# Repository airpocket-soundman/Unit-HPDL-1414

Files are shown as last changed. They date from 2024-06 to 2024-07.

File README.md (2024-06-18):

# Unit-HPDL-1414
HPDL-1414をM5StackのUnitにする

# BOM
M5Stamp S3
HPDL-1414

# PIN接続

|No|HPDL1414|StampS3|GROVE|
|-|-|-|-|
|1|D6 DATA INPUT|G46|
|2|D5 DATA INPUT|G43|
|3|WR WRITE(1)|G42|
|3|WR WRITE(2)|G44|
|4|A1 DIGIT SELECT|G41|
|5|A0 DIGIT SELECT|G40|
|6|VDD||
|7|GND||
|8|D0 DATA INPUT|G1|
|9|D1 DATA INPUT|G3|
|10|D2 DATA INPUT|G5|
|11|D3 DATA INPUT|G7|
|12|D4 DATA INPUT|G9|
|13|SDA|G13|
|14|SDC|G14|

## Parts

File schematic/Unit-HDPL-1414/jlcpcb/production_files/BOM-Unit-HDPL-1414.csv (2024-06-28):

Comment | Designator | Footprint | LCSC
H1 | M5Unit_Screw_Hole | unit_mounting_hole |  | 0 | 0
J1 | Conn_01x04 | HY2.0-4P |  | 0 | 0
U1 | M5StampS3 | M5StampS3 |  | 0 | 0
U2 | hpdl1414 | HPDL-1414 |  | 0 | 0
U3 | hpdl1414 | HPDL-1414 |  | 0 | 0

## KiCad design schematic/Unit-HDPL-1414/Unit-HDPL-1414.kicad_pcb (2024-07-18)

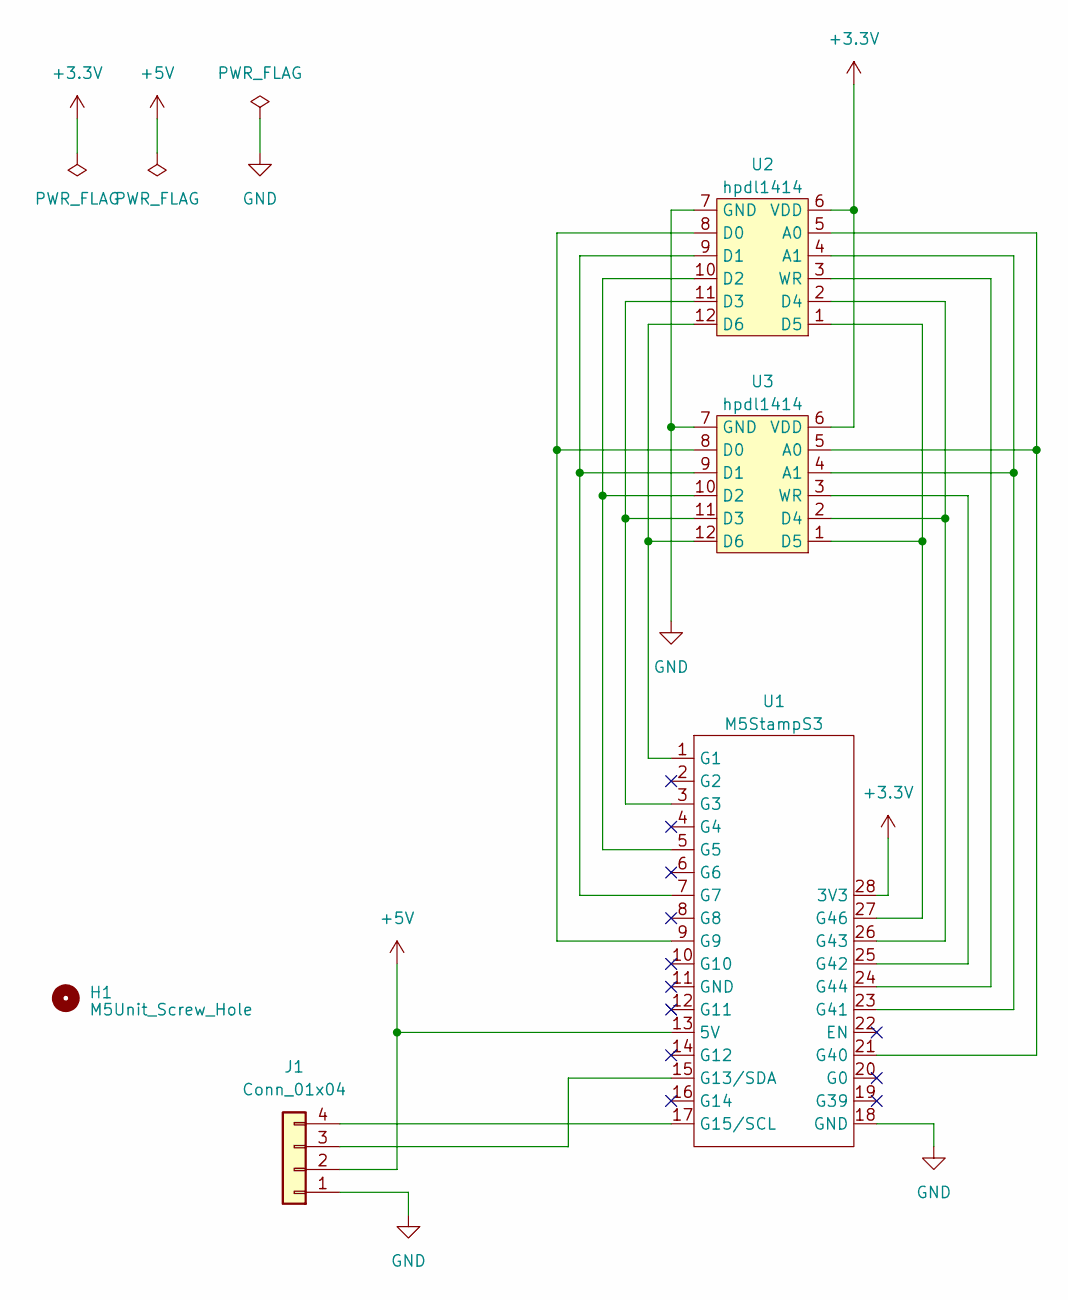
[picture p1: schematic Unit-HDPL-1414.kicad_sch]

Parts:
H1: M5Unit_Screw_Hole; unit_mounting_hole
J1: Conn_01x04; HY2.0-4P
U1: M5StampS3
U2, U3: hpdl1414; HPDL-1414

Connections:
+3.3V: U1.28 (3V3), U2.6 (VDD), U3.6 (VDD)
+5V: J1.2, U1.13 (5V)
GND: J1.1, U1.18 (GND), U2.7 (GND), U3.7 (GND)
unnamed: J1.3, U1.15 (G13/SDA)
unnamed: J1.4, U1.17 (G15/SCL)
unnamed: U1.1 (G1), U2.12 (D6), U3.12 (D6)
unnamed: U1.3 (G3), U2.11 (D3), U3.11 (D3)
unnamed: U1.5 (G5), U2.10 (D2), U3.10 (D2)
unnamed: U1.7 (G7), U2.9 (D1), U3.9 (D1)
unnamed: U1.9 (G9), U2.8 (D0), U3.8 (D0)
unnamed: U1.21 (G40), U2.5 (A0), U3.5 (A0)
unnamed: U1.23 (G41), U2.4 (A1), U3.4 (A1)
unnamed: U1.25 (G42), U3.3 (WR)
unnamed: U1.26 (G43), U2.2 (D4), U3.2 (D4)
unnamed: U1.24 (G44), U2.3 (WR)
unnamed: U1.27 (G46), U2.1 (D5), U3.1 (D5)

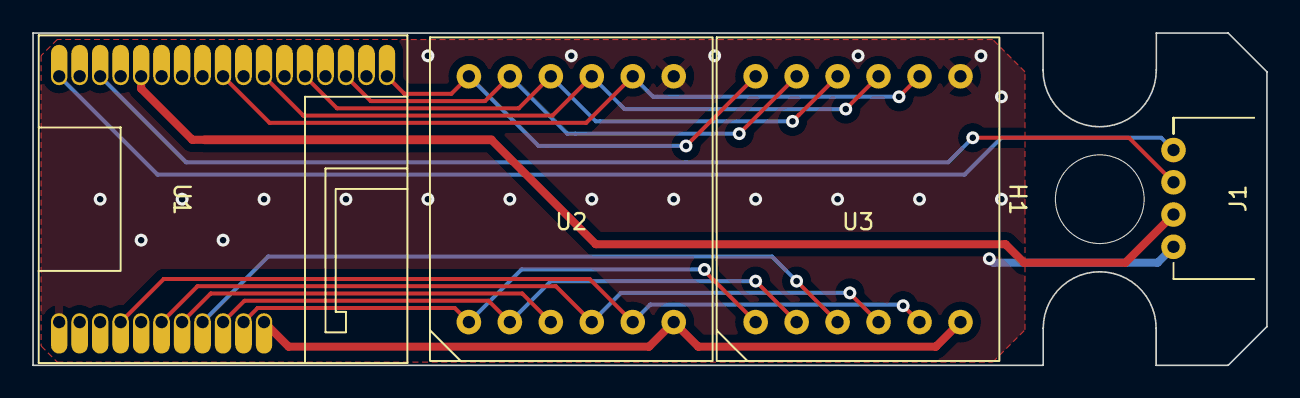
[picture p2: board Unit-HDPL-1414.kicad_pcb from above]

Board: 2 copper layers, 76.5 x 20.6 mm, 5 parts (0 on the bottom side), 16 nets.

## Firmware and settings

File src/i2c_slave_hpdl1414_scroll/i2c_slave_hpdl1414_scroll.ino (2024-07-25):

#if ARDUINO_USB_CDC_ON_BOOT
  #define S3USBSerial Serial
#else
  #if ARDUINO_USB_MODE
    #define S3USBSerial USBSerial
  #else
    #error "Please, board settings -> USB CDC On Boot=Enabled"
  #endif
#endif

#include <stdlib.h>
#include <HPDL1414.h>
#include "Wire.h"

#include <FastLED.h>

#define PIN_LED    21   // 本体フルカラーLEDの使用端子（G21）
#define NUM_LEDS   1    // 本体フルカラーLEDの数
CRGB leds[NUM_LEDS];

//I2C
#define PIN_SDA 13
#define PIN_SCL 15
#define I2C_DEV_ADDR 0x58

//HPDL1414
#define PIN_D0   9
#define PIN_D1   7
#define PIN_D2   5
#define PIN_D3   3
#define PIN_D4  43
#define PIN_D5  46
#define PIN_D6   1
#define PIN_A0  40
#define PIN_A1  41
#define PIN_WR0 44      //1台目のHPDL1414のWRピンに接続するピン
#define PIN_WR1 42      //2台目のHPDL1414のWRピンに接続するピン
//const byte dataPins[7] = {9, 7, 5, 3, 43, 46, 1}; // Segment data pins: D0 - D6
//const byte addrPins[2] = {40, 41};                // Segment address pins: A0, A1
//const byte wrenPins[]  = {44, 42};                // Write Enable pins (left to right)
//HPDL-1414制御用
const byte dataPins[7] = {PIN_D0, PIN_D1, PIN_D2, PIN_D3, PIN_D4, PIN_D5, PIN_D6};	  // ASCIIコードデータ送信用ピン指定 : D0~D6
const byte addrPins[2] = {PIN_A0, PIN_A1 };				                                  // 表示するセグメントのアドレス送信用ピン指定　: A0, A1
const byte wrenPins[]  = {PIN_WR0, PIN_WR1};					                                // 書き込み開始信号送信用ピン指定 :WREN　※HPDL1414を2個使用（8桁表示）するためピンを2本指定。使用するHPDL1414毎にPIN一本追加。

HPDL1414 hpdl(dataPins, addrPins, wrenPins, sizeof(wrenPins));                        //HPDLのインスタンス開始
int delayTime = 300;// スクロールのステップ間の遅延時間（ミリ秒）

String text = "HPDL1414 UNIT";
int displayLength = 8; // 一度に表示できる文字数


uint32_t i = 0;

void onRequest() {
  Wire.print(i++);
  Wire.print(" Packets.");
  S3USBSerial.println("onRequest");
}


void onReceive(int len) {
  S3USBSerial.println("");  // 改行
  S3USBSerial.println("onReceive called");  // デバッグメッセージ
  S3USBSerial.printf("onReceive[%d]: ", len);

  char com[3] = {0};  // 2文字を格納するバッファ（+1は終端用）
  char buffer[33] = {0};  // 残りのデータを格納するバッファ（+1は終端用）
  int comIndex = 0;
  int bufferIndex = 0;
  int totalBytesRead = 0;

  while (Wire.available()) {
    char c = Wire.read();
    totalBytesRead++;
    
    if (totalBytesRead == 1) {
      // 最初の1文字を捨てる
      continue;
    } else if (totalBytesRead >= 2 && totalBytesRead <= 3) {
      // 2文字目から3文字目をcomに格納
      if (c >= 32 && c <= 126) {  // 表示可能なASCII文字のみをバッファに格納
        com[comIndex++] = c;
      }
    } else if (bufferIndex < sizeof(buffer) - 1) {
      // 残りのデータをbufferに格納
      if (c >= 32 && c <= 126) {  // 表示可能なASCII文字のみをバッファに格納
        buffer[bufferIndex++] = c;
      }
    } else {
      // バッファサイズを超えたデータを無視（必要に応じてデバッグ出力可能）
      S3USBSerial.print("*");  // 超過データを視覚的に確認するためのデバッグ出力
    }
  }

  //com[comIndex] = '\0';  // comバッファの終端を設定
  //buffer[bufferIndex] = '\0';  // bufferバッファの終端を設定

  // 受信したデータを表示
  S3USBSerial.print("Command: ");
  S3USBSerial.println(com);
  S3USBSerial.print("Data: ");
  S3USBSerial.println(buffer);
  
  // comの内容に応じて関数を呼び出す
  if (strcmp(com, "S:") == 0) {
    scrollDisplay(buffer);
  } else if (strcmp(com, "F:") == 0) {
    fixedDisplay(buffer);
  } else if (strcmp(com, "D:") == 0) {
    setScrollDelay(buffer);
  }
}

void scrollDisplay(char buffer[129]){
  S3USBSerial.print("scroll func Command: ");
  S3USBSerial.println(buffer);
  hpdl.clear();
  std::string strBuffer(buffer);
  printScrollingText(hpdl, strBuffer.c_str(), displayLength, delayTime);
}

void fixedDisplay(char buffer[33]){
  S3USBSerial.print("fix func Command: ");
  S3USBSerial.println(buffer);
  // バッファが9文字以上の場合、9文字目以降をカット
  if (strlen(buffer) > 8) {
      buffer[8] = '\0';  // 9文字目の位置にヌル文字を挿入して文字列を終了
  }

  hpdl.clear();
  hpdl.print(buffer);
}

void setScrollDelay(char buffer[33]){
  delayTime = atoi(buffer);
  S3USBSerial.print("set delay func Command: ");
  S3USBSerial.println(buffer);
}

void setup() {
  S3USBSerial.begin(115200);
  //while (!S3USBSerial) {
  //  ; // シリアルポートが利用可能になるまで待機
  //}

  FastLED.addLeds<WS2812B, PIN_LED, GRB>(leds, NUM_LEDS);
  leds[0] = CRGB(40, 40, 40);   // 白色（赤, 緑, 青）※3色それぞれの明るさを0〜255で指定


  //HDPL1414表示消去
  hpdl.begin();
  hpdl.printOverflow(true);
  hpdl.clear();

  /*
  delay(1000);
  hpdl.print("0123456789");
  delay(1000);
  hpdl.clear();
  delay(1000);
  hpdl.print("abcdefgh");
  delay(1000);
  hpdl.clear();
  delay(1000);
  hpdl.print("ABCDEFGH");
  delay(1000);
  hpdl.clear();
  delay(1000);
  hpdl.print("FFFFFFFF123");
  delay(1000);
  hpdl.clear();
  */
  
  
  printScrollingText(hpdl, text, displayLength, delayTime);
  setupI2CSlaveDevice();
  
}

void loop() {
  S3USBSerial.print(".");
  //delay(1000);

  /*
  leds[0] = CRGB::Red;
  FastLED.show();
  delay(500);
  leds[0] = CRGB::Black;
  FastLED.show();
  delay(500);
  leds[0] = CRGB(40, 40, 40);
  FastLED.show();
  delay(500);
  */
}

void setupI2CSlaveDevice(){

  S3USBSerial.println("Setup starting...");
  S3USBSerial.print("Start as I2C 0x");
  S3USBSerial.println(I2C_DEV_ADDR, HEX);
  
  Wire.setPins(PIN_SDA, PIN_SCL);
  Wire.onReceive(onReceive);
  Wire.onRequest(onRequest);
  Wire.begin((uint8_t)I2C_DEV_ADDR);

  S3USBSerial.println("I2C initialized");
}


void printScrollingText(HPDL1414& hpdl, const String& text, int displayLength, int delayMs) {
    // 表示をスムーズにするために、テキストの先頭と末尾にスペースを追加
    String paddedText = String("        ") + text + String("        "); // 前後に8文字分のスペースを追加

    for (int i = 0; i < paddedText.length() - displayLength + 1; ++i) {
        // 表示する部分文字列を抽出
        String subText = paddedText.substring(i, i + displayLength);
        
        // hpdl.printを使って表示
        hpdl.print(subText);
        
        // 指定された遅延時間だけ待機
        delay(delayTime);
    }
}

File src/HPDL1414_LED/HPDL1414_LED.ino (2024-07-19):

#include <FastLED.h>

#define PIN_LED    21   // 本体フルカラーLEDの使用端子（G21）
#define NUM_LEDS   1    // 本体フルカラーLEDの数

CRGB leds[NUM_LEDS];


void setup() {
  USBSerial.begin(9600);
  FastLED.addLeds<WS2812B, PIN_LED, GRB>(leds, NUM_LEDS);
  leds[0] = CRGB(40, 40, 40);   // 白色（赤, 緑, 青）※3色それぞれの明るさを0〜255で指定
}

//赤 -> 消える -> 白を繰り返す
void loop() { 
  // Turn the LED on, then pause
  leds[0] = CRGB::Red;
  FastLED.show();
  delay(500);
  USBSerial.println("RED");

  // Now turn the LED off, then pause
  leds[0] = CRGB::Black;
  FastLED.show();
  delay(500);

  // Turn the LED on, then pause
  leds[0] = CRGB(40, 40, 40);
  FastLED.show();
  delay(500);
}

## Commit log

2024-06-18 schematic作成中
    [Unit-HDPL-1414.kicad_pcb, Unit-HDPL-1414.kicad_sch]
2024-06-25 schematic src
    [BOM-Unit-HDPL-1414.csv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]
2024-06-26 slave master コード作成中
2024-06-28 基板ピン配置ミス修正
    [BOM-Unit-HDPL-1414.csv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]
2024-07-18 回路図修正
    [Unit-HDPL-1414-CuBottom.gbr, Unit-HDPL-1414-CuTop.gbr, Unit-HDPL-1414-EdgeCuts.gbr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]
2024-07-18 コード見直し等
2024-07-19 カスタムブロック修正
